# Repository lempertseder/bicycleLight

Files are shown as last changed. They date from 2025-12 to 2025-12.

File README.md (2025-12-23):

# 🚴‍♂️ Automatic Bicycle Light

open-source-project with an STM32C011, mpu6050 and 3d-printed case. Switches Light on when bicycle moves. Switches off after 1 minute standing still.

[ [ [

## Features

- Movement detection via MPU6050 (measurement each 2 seconds)
- Automatic On when movement detected, Off after standing still and timeout
- STM32-based (STM32CubeMX IOC included)
- 3D-printed case
- Low sysclk for low power consumption: ~1mA idle current (mcu + mpu6050)

## Overview

- [Technical Stack](#technical-stack)
- [Quickstart](#quickstart)
- [BOM](#bom)
- [Build Instruction](#build-instruction)
- [Firmware Flashing](#firmware-flashing)
- [License Overview](#license-overview)
- [Known Problems](#known-problems)
- [Contribute](#contribute)

## Technical Stack

| Component | Technology |
| :-- | :-- |
| MCU | STM32C011 (STM32CubeMX IOC) |
| Sensor | MPU6050 (I²C) |
| Case | PLA, STL-Files |
| Firmware | STM, MIT-licensed |

## BOM
| Component | Reichelt No. | 
| :-- | :-- |
| STM32C011 mcu | STM32C011J6M6 |
| mpu6050 | DEBO HMC5883L 2 |
| step-down converter | LMO78_03-1.0 |
| Adapterboard SO8 | RE 899 |
| BC547, npn bjt | ... |
| 1k THT base resistor | ... |
| M3 countersunk screws | SKS M3X20-50 |
| M3 hot melt insert thread | ... |
| cable tie | SHVP BS18-10002 |

- for flashing: ST-link V3 or eval board (like NUCLEO-F746ZG)
- lipo battery, case works with 3S battery from an RC-Car (102mm x 34mm x 23mm)
- front and rear LED light (e.g. battery powered light from a supermarket/hardware store)

## Quickstart

1. **Build Hardware**: solder MCU on SO8-Adapterboard if needed, print STLs (0.2mm Layer, 20% Infill)
2. **Flash firmware**: ST-link V3 or STM-eval board
3. **Connect**: Connect to LiPo battery and front/rear light
3. **Test**: move bicycle → Lampe ON, 1min still → OFF
```
STLs: mechanics/
```

## Build instruction

### 1. 3D-Print

```
Case: mechnics/bicycleLight_case_r2.stl (Supports: No)
Cover: mechnics/bicycleLight_cover.stl
Printsettings: 0.2mm, 210°C extruder, 60°C heat bed
```

### 2. Adapter PCB

use SO8 adapter pcb if needed

### 3. Cabling
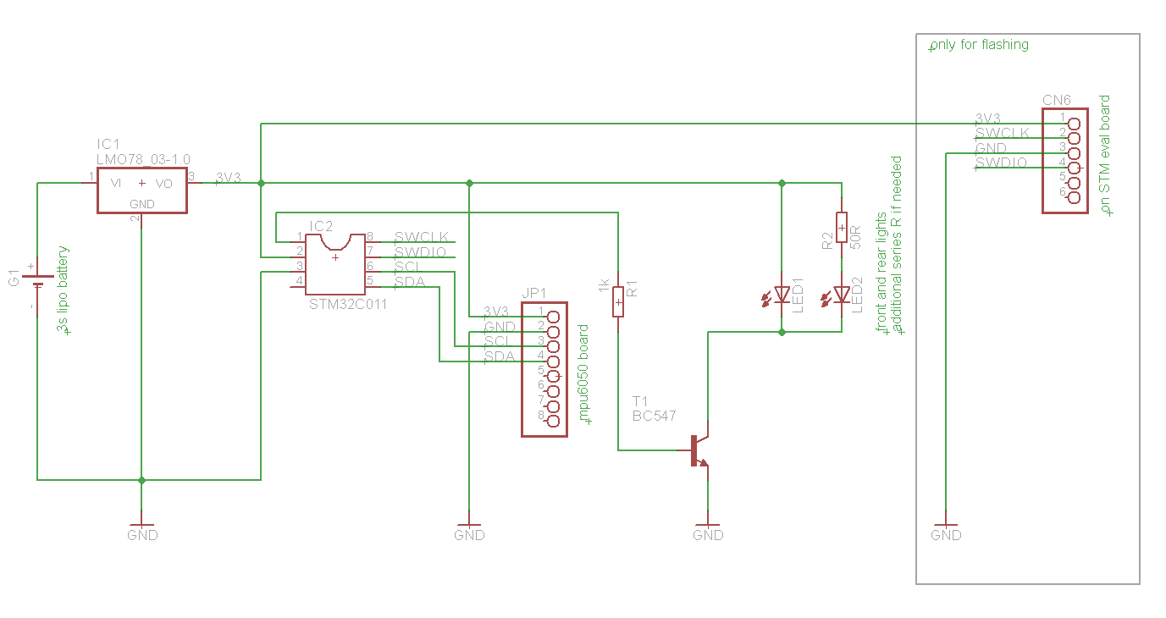
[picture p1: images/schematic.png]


| Name | SO8 pin no. | STM gpio name |
| :-- | :-- | :-- |
| LED-Light transistor | → Pin 1 | PC14 |
| MPU6050 SDA | → Pin 5 | PA8 |
| MPU6050 SCL | → Pin 6 | PA12 |
| SWDIO (flashing) | → Pin 7 | |
| SWCLK (flashing) | → Pin 8 | |

## Flashing Hardware
e.g. ST-Link V2/3 or STM eval kit:
- NUCLEO-F303RE (reichelt, not tested)
- NUCLEO-F746ZG (tested)
- NUCLEO-F446ZE (reichelt, not tested, but same base as F746ZG)

on MB1137 based eval boards (F746ZG, F446ZE, etc.) connector (CN6) can be used to program MCUs.
headers on CN4 needs to be removed to use external programming (not the mcu on the eval board).
pinout of the CN6:

| CN6 pin | connect to STM mcu | function |
| :-- | :-- | :-- |
| 1 | → Pin 2 | Vdd feedback (connect here also 3V3 from the eval board to power the external MCU, e.g. pin 7 from CN8) |
| 2 | → Pin 8 | SWCLK |
| 3 | → Pin 3 | GND |
| 4 | → Pin 7 | SWDIO |
| 5 | n.c. | NRST |
| 6 | n.c. | SWO |

## Firmware Flashing

use STM32CubeProgrammer
pre-built elf in binary folder
- connect
- choose Erase & Programming
- browse to the binary folder and choose the elf file
- Start programming

## License Overview

| Component | License | Files |
| :-- | :-- | :-- |
| Firmware (own) | MIT | `firmware/` |
| STM32CubeMX Code | BSD-3-Clause | `*.ioc`, generated HAL-Code |
| STLs/Case | CC-BY-SA-3.0 | `mechanics/` |
| Images | CC-BY-SA-4.0 | `images/` |

See [LICENSE](LICENSE).

## Known Problems

- **waterproof**: not perfectly waterproof. mount with cover at the bottom to be waterproof against rain at least.

See [Issues](https://github.com/lempertseder/bicycleLight/issues).

## Contribute

1. Fork this Repo
2. Create Feature-Branch (`git checkout -b feature/mpu-opti`)
3. Commit your changes (`git commit -m 'MPU Optimierung'`)
4. Push (`git push origin feature/mpu-opti`)
5. Create Pull Request

## Acknowledgments

- MPU6050 Motion-Detect Tutorial
- OSHWA License-Helper

***

**⭐ Star this Repo, if it helps!**
**Questions?** [Issues](https://github.com/lempertseder/bicycleLight/issues/new)

***

*© 2025 mle *[^1][^5]
<span style="display:none">[^10][^2][^3][^4][^6][^7][^8][^9]</span>

<div align="center">⁂</div>

[^1]: https://github.com/othneildrew/Best-README-Template

[^2]: https://github.com/topics/readme-template

[^3]: https://gist.github.com/DomPizzie/7a5ff55ffa9081f2de27c315f5018afc

[^4]: https://github.com/cfpb/open-source-project-template/blob/main/README.md

[^5]: https://github.com/dbader/readme-template

[^6]: https://dev.to/sumonta056/github-readme-template-for-personal-projects-3lka

[^7]: https://github.com/sfbrigade/data-science-wg/blob/master/dswg_project_resources/Project-README-template.md

[^8]: https://www.reddit.com/r/programming/comments/l0mgcy/github_readme_templates_creating_a_good_readme_is/

[^9]: https://www.daytona.io/dotfiles/how-to-write-4000-stars-github-readme-for-your-project

[^10]: https://github.com/matiassingers/awesome-readme

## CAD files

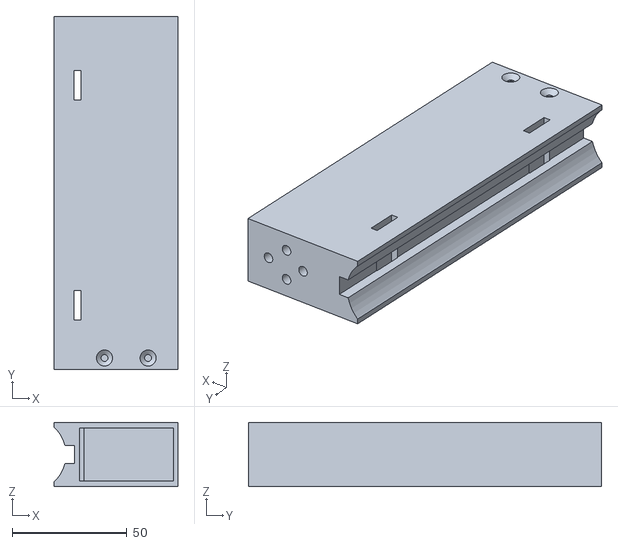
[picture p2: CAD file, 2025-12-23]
mechanics/bicycleLight_case_r2.stl
54.0 x 154.0 x 28.0

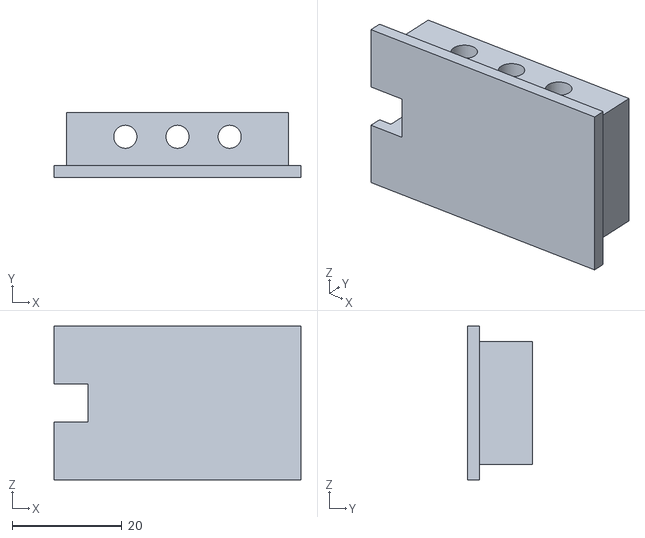
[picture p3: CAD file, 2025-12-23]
mechanics/bicycleLight_cover.stl
45.0 x 11.8 x 28.0

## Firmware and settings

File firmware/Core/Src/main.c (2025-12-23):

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
/* Includes ------------------------------------------------------------------*/
#include "main.h"

/* USER CODE BEGIN Includes */
#include "debugLog.h"
#include "i2c_bitbang.h"
/* USER CODE END Includes */

/* USER CODE BEGIN PD */

#define MPU_ADDR   				0x68
#define MPU_REG_ACCEL_X        	0x3b
#define MPU_REG_ACCEL_Y        	0x3d
#define LightSwitch_Pin        	GPIO_PIN_14
#define LightSwitch_GPIO_Port  	GPIOC


/* USER CODE END PD */


/* USER CODE BEGIN PV */

int16_t xAccelArray[8];
int16_t yAccelArray[8];
uint8_t accelArray_pos=0;

/* USER CODE END PV */

void SystemClock_Config(void);
static void MX_GPIO_Init(void);
/* USER CODE BEGIN 0 */

int16_t getMedian(uint8_t arraySel){
	int16_t sum=0;
	for(uint8_t i=0;i<8;i++){
		if (arraySel == 0)
			sum += xAccelArray[i];
		else
			sum += yAccelArray[i];

	}
	return sum/8;
}

/* USER CODE END 0 */

/**
  * @brief  The application entry point.
  * @retval int
  */
int main(void)
{

  /* MCU Configuration--------------------------------------------------------*/

  /* Reset of all peripherals, Initializes the Flash interface and the Systick. */
  HAL_Init();

  /* Configure the system clock */
  SystemClock_Config();

  /* Initialize all configured peripherals */
  MX_GPIO_Init();
  /* Infinite loop */
  /* USER CODE BEGIN WHILE */
  uint16_t counter = 0, onCnt = 0, moveDetectCnt = 0;
  i2cWrite2bytes(MPU_ADDR, 0x6b, 0x00); // dummy write after power up
  i2cWrite2bytes(MPU_ADDR, 0x6b, 0x00); // PWR_MGMT_1 register - wake up
  i2cWrite2bytes(MPU_ADDR, 0x19, 0xff); // sample rate divider - highest divider
  i2cWrite2bytes(MPU_ADDR, 0x1c, 0x18); // Accel config register - scale to +/-16g

  //#define USE_DEBUG_LOG // debug log pin and light switch uses the same pin

  while (1)
  {
	  if (onCnt>0){
		  onCnt-=2;
	  }

	  i2cWrite2bytes(MPU_ADDR, 0x6b, 0x00); // PWR_MGMT_1 register - wake up
	  i2cWrite1byte(MPU_ADDR, MPU_REG_ACCEL_X);
	  int16_t accel_x = (int16_t)i2cRead2bytes(MPU_ADDR);
	  i2cWrite1byte(MPU_ADDR, MPU_REG_ACCEL_Y);
	  int16_t accel_y = (int16_t)i2cRead2bytes(MPU_ADDR);
	  i2cWrite2bytes(MPU_ADDR, 0x6b, 0x40); // PWR_MGMT_1 register - sleep

	  int16_t xDiff = getMedian(0) - accel_x;
	  int16_t yDiff = getMedian(1) - accel_y;

	  if (xDiff > 200 || xDiff < -200 || yDiff > 200 || yDiff < -200){ // movement detected
		  moveDetectCnt++;
		  if (moveDetectCnt>1)
			  onCnt=60; // set light on time
	  }
	  else
		  moveDetectCnt = 0;

	  // add to median-calc-array
	  xAccelArray[accelArray_pos] = accel_x;
	  yAccelArray[accelArray_pos] = accel_y;
	  accelArray_pos++;
	  if (accelArray_pos>7)
		  accelArray_pos=0;

	  // log
	  #ifdef USE_DEBUG_LOG
	  counter++;
	  sendDebugByte(counter>>8);
	  sendDebugByte(counter);
	  sendDebugByte(accel_x >> 8);
	  sendDebugByte(accel_x & 0xff);
	  sendDebugByte(accel_y >> 8);
	  sendDebugByte(accel_y & 0xff);
	  sendDebugByte(onCnt>>8);
	  sendDebugByte(onCnt);
	  #else
	  if (onCnt > 0){
		  HAL_GPIO_WritePin(LightSwitch_GPIO_Port, LightSwitch_Pin, GPIO_PIN_SET); // switch on
	  }
	  else{
		  HAL_GPIO_WritePin(LightSwitch_GPIO_Port, LightSwitch_Pin, GPIO_PIN_RESET); // switch off
	  }
	  #endif

	  HAL_Delay(2000);
    /* USER CODE END WHILE */

    /* USER CODE BEGIN 3 */
  }
  /* USER CODE END 3 */
}

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


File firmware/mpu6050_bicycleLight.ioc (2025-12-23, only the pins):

Mcu.UserName=STM32C011J6Mx
PA13.Signal=DEBUG_SWDIO
PA14-BOOT0.Signal=DEBUG_SWCLK
PA8.Signal=GPIO_Output

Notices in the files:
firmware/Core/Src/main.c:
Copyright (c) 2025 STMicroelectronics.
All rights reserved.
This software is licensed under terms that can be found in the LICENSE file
